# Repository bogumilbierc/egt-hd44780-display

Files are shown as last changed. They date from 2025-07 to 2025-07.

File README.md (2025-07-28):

# EGT HD44780 Display #

EGT display using Arduino with HD44780 screen and four MAX6675 EGT amplifiers

## Preview ##

### In car ###

preview_in_car

### MAX6675 modules with wiring ###

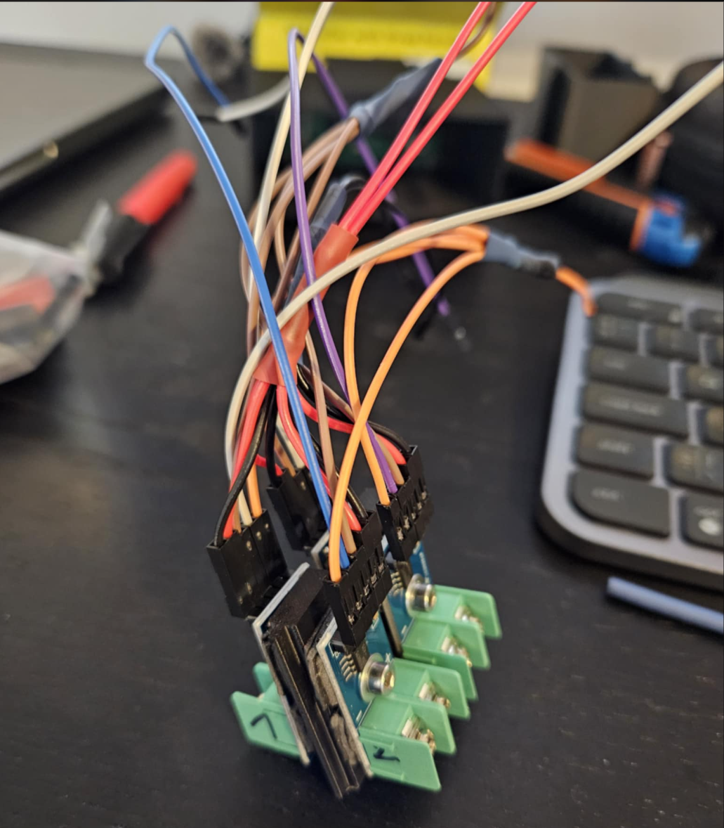
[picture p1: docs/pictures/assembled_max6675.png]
assembled_max6675


### Back of the case, modules exploded ###

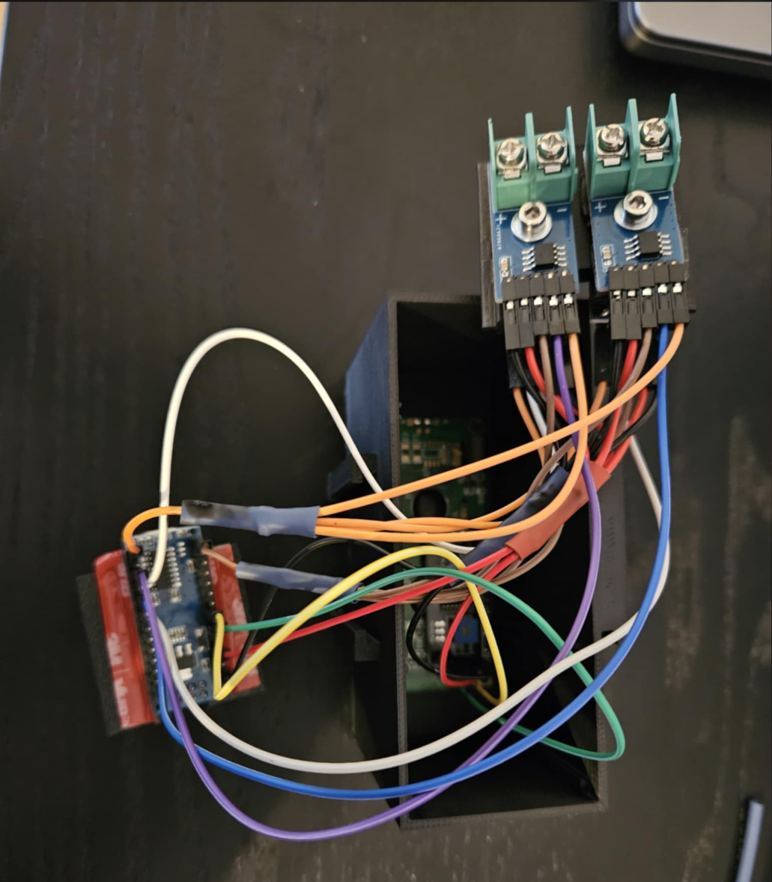
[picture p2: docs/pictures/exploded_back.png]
assembled preview_back


### Back of the case, all modules inside ###

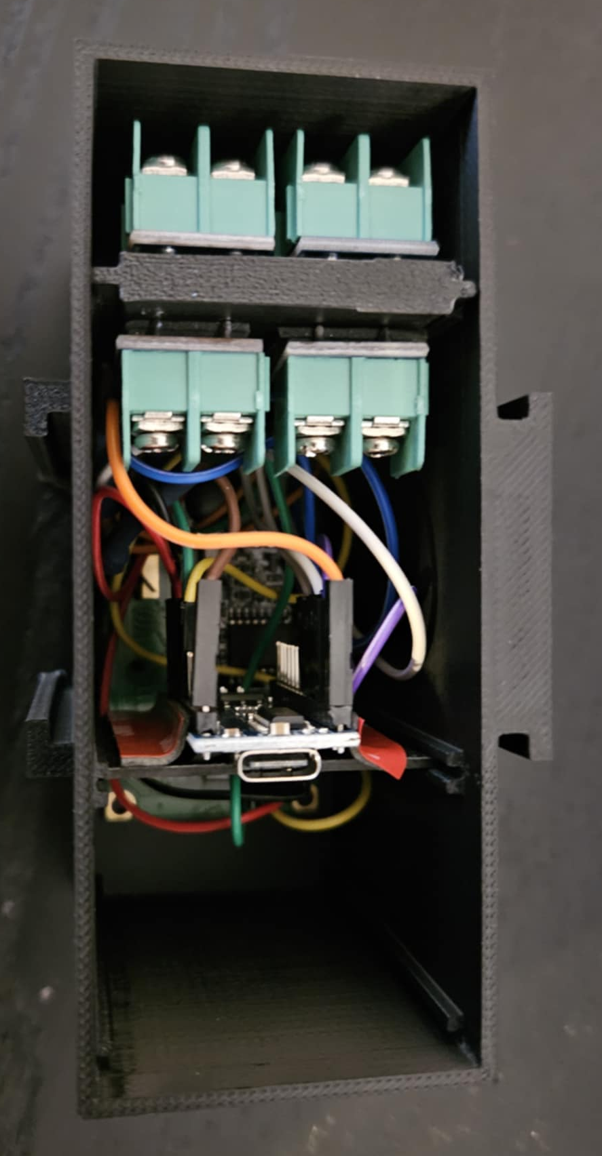
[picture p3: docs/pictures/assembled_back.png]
assembled preview_back


## Mounting in the car ##

It is designed to lock on to supports and to be able to be stacked together with EMU dash
from: https://github.com/bogumilbierc/ecumaster-emu-hd44780-display

## Elements ##

- Arduino Nano
- 4 x MAX6675
- HD44780 LCD with I2C interface
- 4 EGT K-Type probes

## Powering in the car ## 

It is designed to be powered via the USB port using a regular car charger.

## Arduino IDE setup ##

- Install LiquidCrystal_I2C library
- Install MAX6675 (by Adafruit)

## Hardware connections ##

### Arduino <> Display ###

| Arduino | Display |
|---|---|
| 5V | VCC |
| GND | GND |
| A4 | SDA |
| A5 | SCL |

### Arduino <> MAX6675 ###

| Arduino | MAX6675 #1 | MAX6675 #2 | MAX6675 #3 | MAX6675 #4 | 
|---|---|---|---|---|
| 5V | VCC | VCC | VCC | VCC |
| GND | GND | GND | GND | GND |
| D13 | SCK | SCK | SCK | SCK |
| D12 | SO | SO | SO | SO |
| D7 | CS | - | - | - |
| D8 | - | CS | - | - |
| D9 | - | - | CS | - |
| D10 | - | - | - | CS |

## Case ##

Case is a FreeCad project that can be 3D printed.

### Preview ###

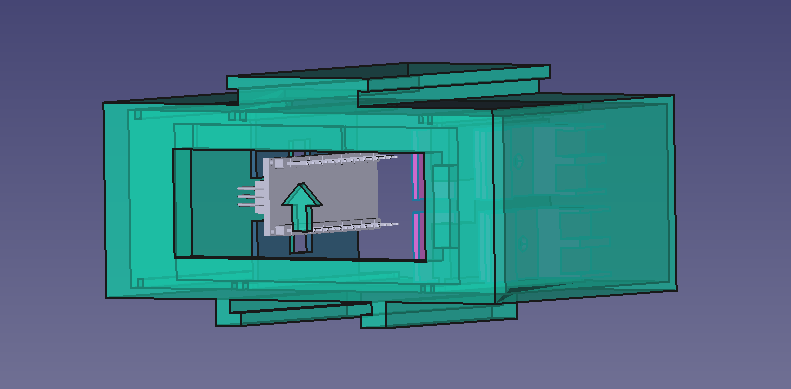
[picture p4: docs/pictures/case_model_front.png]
case model_preview_front


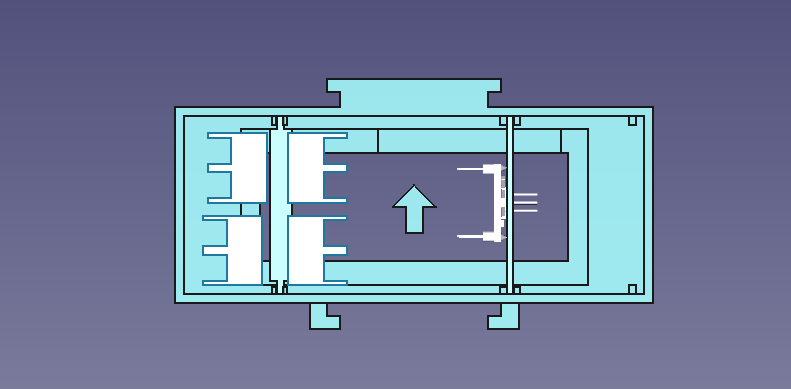
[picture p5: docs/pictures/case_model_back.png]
case model_preview_back


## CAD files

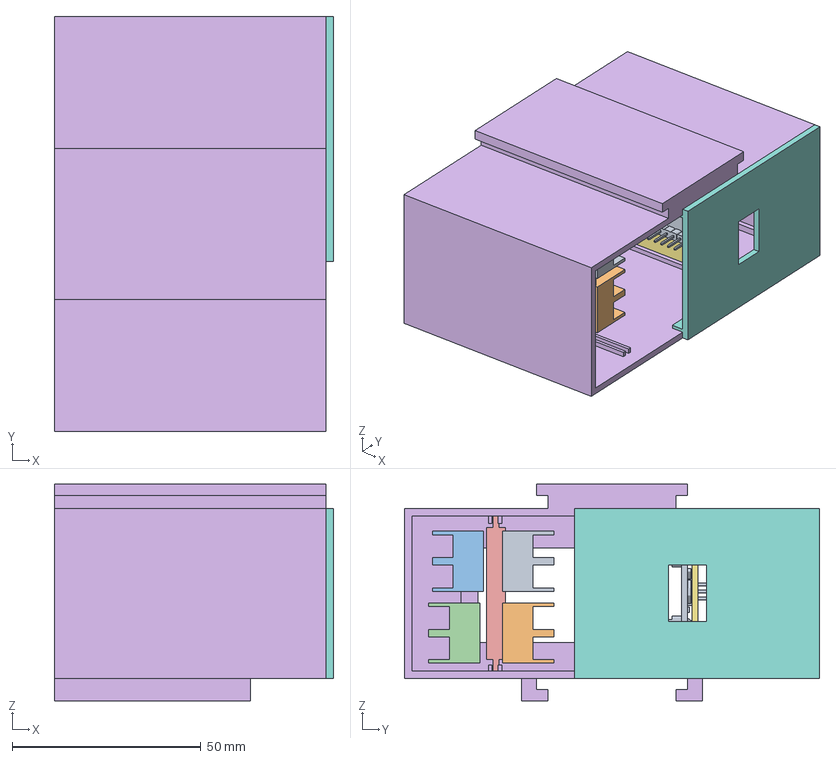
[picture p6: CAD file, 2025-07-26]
case/egt_controller_case_vertical_shelf.FCStd
74.0 x 110.0 x 57.5 mm
MAX6675
MAX6675_COPY
MAX6675_COPY001
MAX6675_COPY002
VerticalShelfForMax6675
MainCaseWithScreenCut
VerticalShelfForArduino
RearLid
Arduino v5

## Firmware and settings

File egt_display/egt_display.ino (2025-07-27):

/**
* Arduino EGT Display
*/
#define DEBUG_ENABLED false

#include <Wire.h>
#include <LiquidCrystal_I2C.h>

#include <max6675.h>

const int THERMO_SLAVE_OUT = 12;
const int THERMO_CLOCK = 13;

const int THERMO_CS_BANK_1 = 7;
const int THERMO_CS_BANK_2 = 8;
const int THERMO_CS_BANK_3 = 9;
const int THERMO_CS_BANK_4 = 10;

char intStringBuff[4];

LiquidCrystal_I2C lcd(0x27, 16, 2);

MAX6675 thermocoupleBank1(THERMO_CLOCK, THERMO_CS_BANK_1, THERMO_SLAVE_OUT);
MAX6675 thermocoupleBank2(THERMO_CLOCK, THERMO_CS_BANK_2, THERMO_SLAVE_OUT);
MAX6675 thermocoupleBank3(THERMO_CLOCK, THERMO_CS_BANK_3, THERMO_SLAVE_OUT);
MAX6675 thermocoupleBank4(THERMO_CLOCK, THERMO_CS_BANK_4, THERMO_SLAVE_OUT);

void setup() {
  setupScreen();

#if DEBUG_ENABLED == true
  Serial.begin(9600);
  Serial.println("MAX6675 test");
#endif

  // wait for MAX chip to stabilize
  delay(500);

  // set all chips high
  setAllPinsToHigh();
}

void loop() {
  printFirstLine();
  printSecondLine();
}

void setupScreen() {
  lcd.init();
  lcd.backlight();
  lcd.clear();
  printSplashScreen();
}

void printSplashScreen() {
  lcd.home();
  lcd.print("EGT...");
  delay(100);
  lcd.setCursor(0, 1);  //jump to new line
  lcd.print("        ...QUACK");
  delay(100);
  lcd.clear();
}

void printFirstLine() {
  lcd.home();
  lcd.print("T1:");
  printFourDigitInt(getEgt(thermocoupleBank1, 1));

  lcd.print(" T2:");
  printFourDigitInt(getEgt(thermocoupleBank2, 2));
}

void printSecondLine() {
  lcd.setCursor(0, 1);  //jump to new line
  lcd.print("T3:");
  printFourDigitInt(getEgt(thermocoupleBank3, 3));

  lcd.print(" T4:");
  printFourDigitInt(getEgt(thermocoupleBank4, 4));
}

void printFourDigitInt(int value) {
  sprintf(intStringBuff, "%4d", value);
  lcd.print(intStringBuff);
}

int getEgt(MAX6675 thermocouple, int bankIndex) {
  float tempCelsius = thermocouple.readCelsius();

#if DEBUG_ENABLED == true
  Serial.print("EGT");
  Serial.println(bankIndex);
  Serial.println(tempCelsius);
#endif

  setAllPinsToHigh();  // this should be redundant, as library does set the pin to HIGH, but...
  delay(300);          // to make sure that MAX6675 stops emitting data to the bus
  return int(trunc(tempCelsius));
}

void setAllPinsToHigh() {
  digitalWrite(THERMO_CS_BANK_1, HIGH);
  digitalWrite(THERMO_CS_BANK_2, HIGH);
  digitalWrite(THERMO_CS_BANK_3, HIGH);
  digitalWrite(THERMO_CS_BANK_4, HIGH);
}

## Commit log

2025-07-08 Add dummy script that prints quack on screen
2025-07-09 Add first sketchups of case - just egt amplifier rough model
    [case.FCStd]
2025-07-09 Add rough sketch of hd44780
    [case.FCStd]
2025-07-09 Add front facia for screen case; Rotate screen to match orientation of other elements
    [case.FCStd]
2025-07-09 Remove cutout for screen - it can be done by substracting two bodies; Add side walls
    [case.FCStd]
2025-07-09 Add support for shelf in the middle of the case
    [case.FCStd]
2025-07-09 Rename pad for middle shelf support
    [case.FCStd]
2025-07-09 Add standoff for bottom mount pad
    [case.FCStd]
2025-07-09 Add left bottom sidemount pad
    [case.FCStd]
2025-07-09 Add right bottom side mount pad
    [case.FCStd]
2025-07-09 Add slider mount at the top to mount quack screen
    [case.FCStd]
2025-07-09 Make pins standout for screen bigger to allow for cleaner cut into the case
    [case.FCStd]
2025-07-09 Add case with verical shelf for egt amplifiers
    [egt_controller_case_vertical_shelf.FCStd]
2025-07-09 Add shelf to case
    [egt_controller_case_vertical_shelf.FCStd]
2025-07-15 Add provisions for shelf for arduino
    [egt_controller_case_vertical_shelf.FCStd]
2025-07-15 Add additional shelf slots
    [egt_controller_case_vertical_shelf.FCStd]
2025-07-15 Add holes for screws and cables in shelf for EGT amplifiers; Cutout screen from main case
    [egt_controller_case_vertical_shelf.FCStd]
2025-07-23 Make shelf smaller
    [egt_controller_case_vertical_shelf.FCStd]
2025-07-26 Make case 2cm deeper
    [egt_controller_case_vertical_shelf.FCStd]
2025-07-26 Make slots for shelfs wider
    [egt_controller_case_vertical_shelf.FCStd]
2025-07-26 Make shelfes slots longer
    [egt_controller_case_vertical_shelf.FCStd]
2025-07-26 Make vertical shelf thicker so that egt amplifier do not make a short between each other
    [egt_controller_case_vertical_shelf.FCStd]
2025-07-26 Rename shelf for egt amplifiers
    [egt_controller_case_vertical_shelf.FCStd]
2025-07-26 Add Vertcal shelf for arduino
    [egt_controller_case_vertical_shelf.FCStd]
2025-07-26 Add rear lid to case
    [egt_controller_case_vertical_shelf.FCStd]
2025-07-26 Remove legacy case
    [case.FCStd]
